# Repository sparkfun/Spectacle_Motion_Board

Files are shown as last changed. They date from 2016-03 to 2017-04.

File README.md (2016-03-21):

SparkFun AutoDriver Libraries
==========

Libraries for using the AutoDriver in various environments

Directory Contents
-------------------
* **/Arduino** - [Arduino IDE](http://www.arduino.cc/en/Main/Software) library and example files

License Information
-------------------
This product is open source! 
The code is beerware; if you see me (or any other SparkFun employee) at the local, and you've found our code helpful, please buy us a round!
Please use, reuse, and modify these files as you see fit. Please maintain attribution to SparkFun Electronics and release anything derivative under the same license.

Distributed as-is; no warranty is given.

- Your friends at SparkFun.

BUILD INSTRUCTIONS:
---------------------
While we make every effort to keep our library repositories up-to-date with the product repositories, it may be a good idea to update the libraries to the latest version.

To get the most up-to-date version of the library, you must use the following git subtree commands.

git subtree add -P Libraries/Arduino --squash https://github.com/sparkfun/SparkFun_AutoDriver_Arduino_Library master

git subtree pull -P Libraries/Arduino --squash https://github.com/sparkfun/SparkFun_AutoDriver_Arduino_Library master

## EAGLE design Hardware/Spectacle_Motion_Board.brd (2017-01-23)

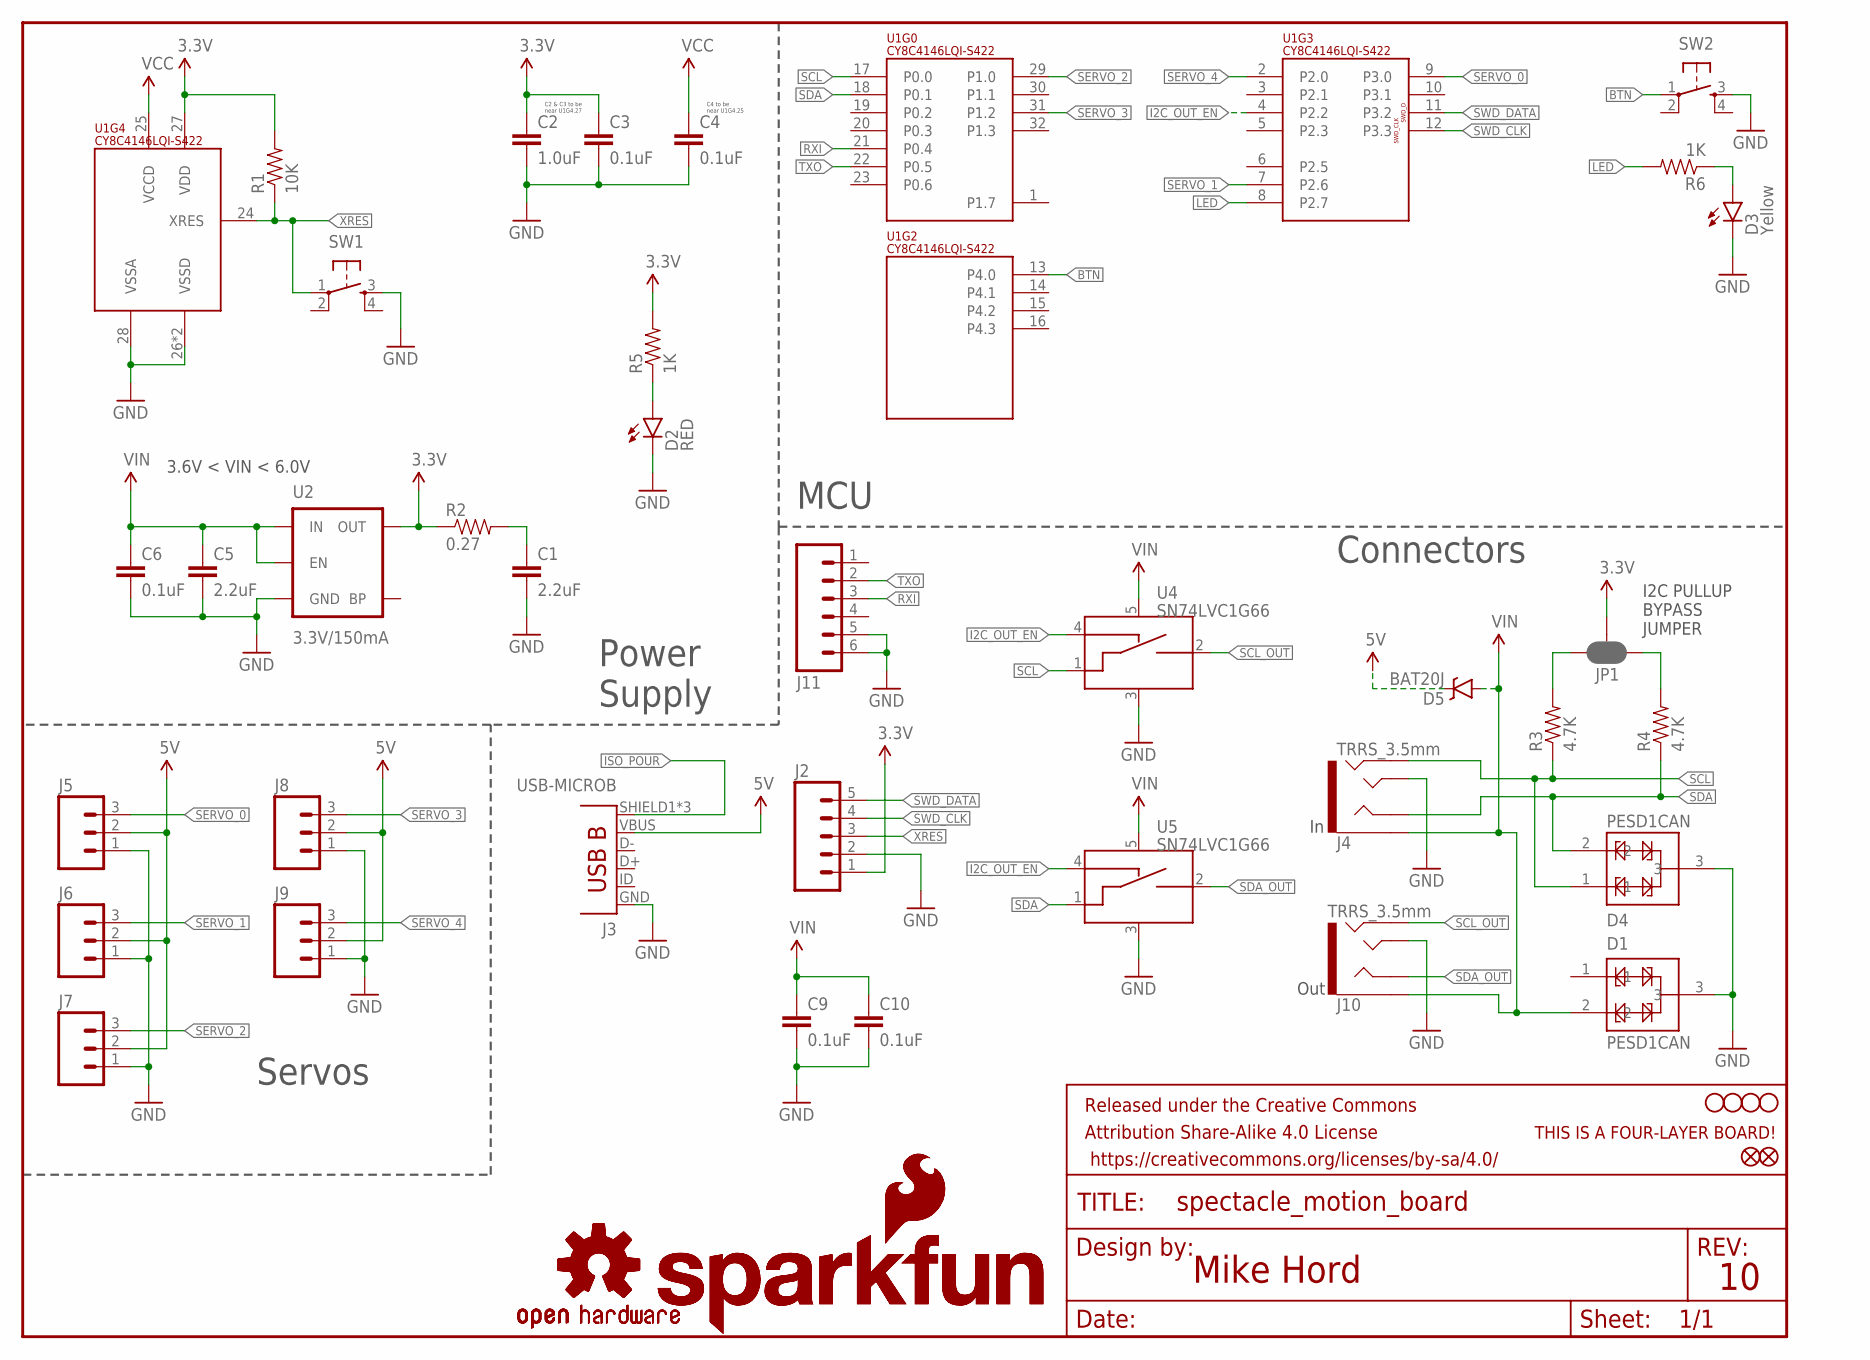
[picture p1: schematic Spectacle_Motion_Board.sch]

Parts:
C1, C5: 2.2uF; 0603-CAP
C2: 1.0uF; 0402-CAP
C3, C4, C6, C9, C10: 0.1uF; 0402-CAP
D1, D4: PESD1CAN; SOT23-3
D2: RED; LED-0603
D3: Yellow; LED-0603
D5: BAT20J; SOD-323
FD1, FD2: FIDUCIALUFIDUCIAL; MICRO-FIDUCIAL
FRAME1: FRAME-LETTER; CREATIVE_COMMONS
H1, H2, H3, H4: STAND-OFF
J2: M05NO_SILK; 1X05_NO_SILK
J3: USB-MICROB; USB-B-MICRO-SMD_V03_RED_PASTE
J4, J10: TRRS_3.5mm; AUDIO_JACK_3.5MM_TRRS_SMD_RA
J5, J6, J7, J8, J9: M03LOCK; 1X03_LOCK
J11: M06NO_SILK_NO_POP; 1X06_NO_SILK
JP1: JUMPER-PAD-3-NC_BY_PASTE; PAD-JUMPER-3-NC_BY_PASTE_YES_SILK_FULL_BOX
LOGO1, LOGO4: OSHW-LOGOS; OSHW-LOGO-S
LOGO2, LOGO3: SFE_LOGO_NAME_FLAME.1_INCH; SFE_LOGO_NAME_FLAME_.1
R1: 10K; 0603-RES
R2: 0.27; 0603-RES
R3, R4: 4.7K; 0603-RES
R5, R6: 1K; 0603-RES
SW1, SW2: SWITCH_SPST_4_PINRECT; TACTILE_SWITCH_SMD_4.6X2.8MM
U1: CY8C4146LQI-S422; QFN-32
U2: 3.3V/150mA; SOT23-5
U4, U5: SN74LVC1G66; SOT23-5
U$1: FOUR_LAYER_WARNING

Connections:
3.3V: C2.1, C3.1, J2.1, JP1.2, R1.2, R2.1, R5.2, U1.27 (VDD), U2.5 (OUT)
5V: D5.C, J3.VBUS, J5.2, J6.2, J7.2, J8.2, J9.2
BTN: SW2.1, U1.13 (P4.0)
GND: C1.2, C2.2, C3.2, C4.2, C5.2, C6.2, C9.2, C10.2, D1.3, D2.C, D3.C, D4.3, J2.2, J3.GND, J4.TIP, J5.1, J6.1, J7.1, J8.1, J9.1, J10.TIP, J11.5, J11.6, SW1.3, SW2.3, U1.26 (VSSD), U1.28 (VSSA), U1.EP (VSSD), U2.2 (GND), U4.3 (VSS), U5.3 (VSS)
I2C_OUT_EN: U1.4 (P2.2), U4.4 (CTRL_IN), U5.4 (CTRL_IN)
ISO_POUR: J3.SHIELD1 (SHIELD), J3.SHIELD2 (SHIELD), J3.SHIELD3 (SHIELD)
LED: R6.2, U1.8 (P2.7)
unnamed: JP1.3, R3.2
unnamed: C1.1, R2.2
unnamed: D2.A, R5.1
unnamed: D3.A, R6.1
unnamed: JP1.1, R4.2
RXI: J11.3, U1.21 (P0.4)
SCL: D4.1, J4.RING2, R3.1, U1.17 (P0.0), U4.1 (A_IN)
SCL_OUT: J10.RING2, U4.2 (A_OUT)
SDA: D4.2, J4.RING1, R4.1, U1.18 (P0.1), U5.1 (A_IN)
SDA_OUT: J10.RING1, U5.2 (A_OUT)
SERVO_0: J5.3, U1.9 (P3.0)
SERVO_1: J6.3, U1.7 (P2.6)
SERVO_2: J7.3, U1.29 (P1.0)
SERVO_3: J8.3, U1.31 (P1.2)
SERVO_4: J9.3, U1.2 (P2.0)
SWD_CLK: J2.4, U1.12 (P3.3)
SWD_DATA: J2.5, U1.11 (P3.2)
TXO: J11.2, U1.22 (P0.5)
VCC: C4.1, U1.25 (VCCD)
VIN: C5.1, C6.1, C9.1, C10.1, D1.2, D5.A, J4.EARTH, J10.EARTH, U2.1 (IN), U2.3 (EN), U4.5 (VCC), U5.5 (VCC)
XRES: J2.3, R1.1, SW1.1, U1.24 (XRES)

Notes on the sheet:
C2 & C3 to be near U1G4.27
C4 to be near U1G4.25
Mike Hord
MCU
Connectors
Servos
Power Supply
3.6V < VIN < 6.0V
I2C PULLUP BYPASS JUMPER
Out

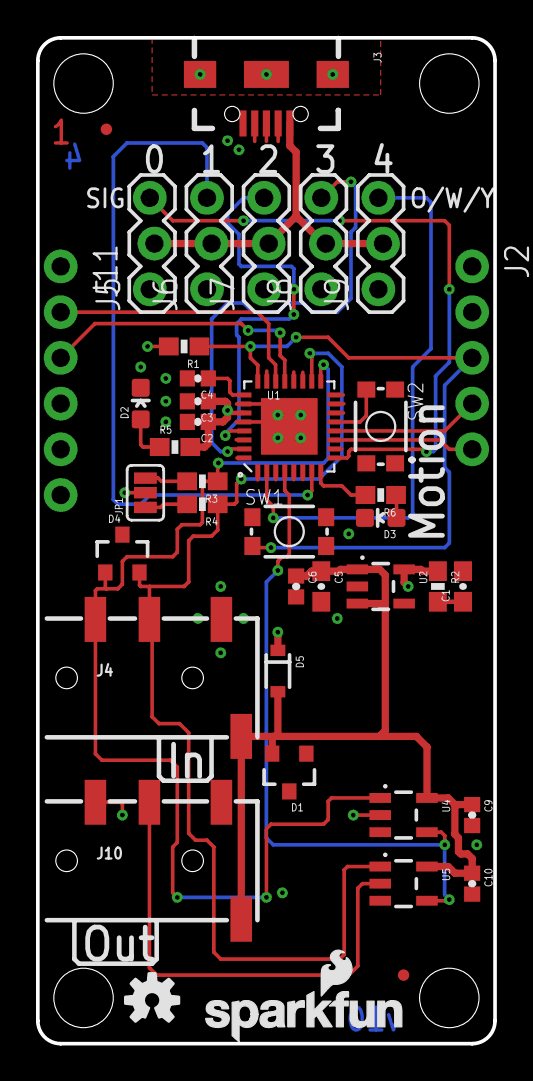
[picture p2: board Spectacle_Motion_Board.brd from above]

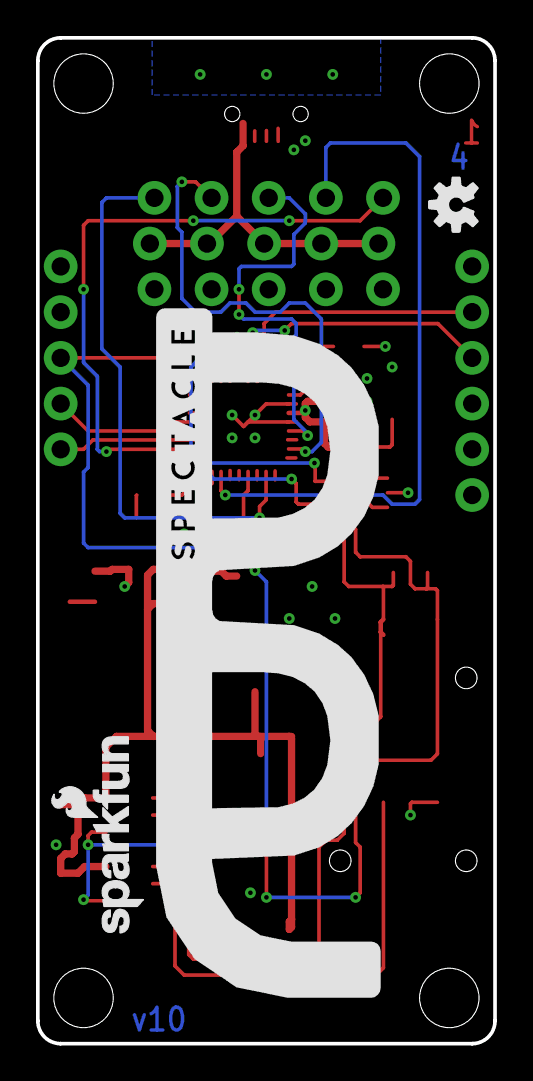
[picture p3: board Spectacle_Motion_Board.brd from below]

Board: 4 copper layers, 25.4 x 55.9 mm, 49 parts (3 on the bottom side), 28 nets.

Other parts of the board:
U$3: SPECTACLE_LOGO_NEGATIVE_1.5X0.5

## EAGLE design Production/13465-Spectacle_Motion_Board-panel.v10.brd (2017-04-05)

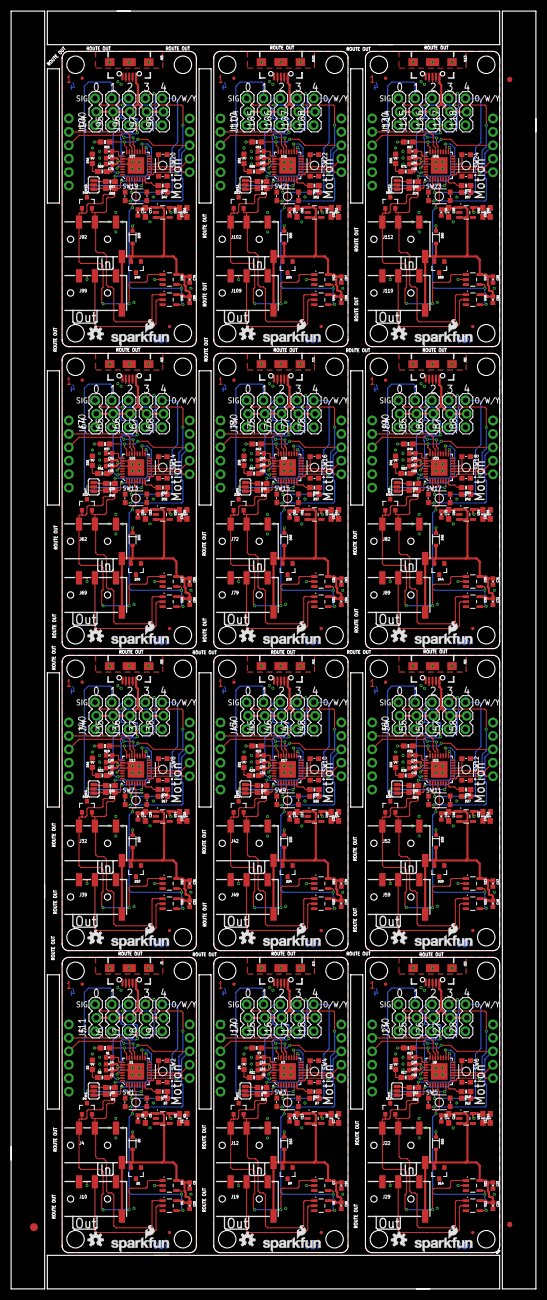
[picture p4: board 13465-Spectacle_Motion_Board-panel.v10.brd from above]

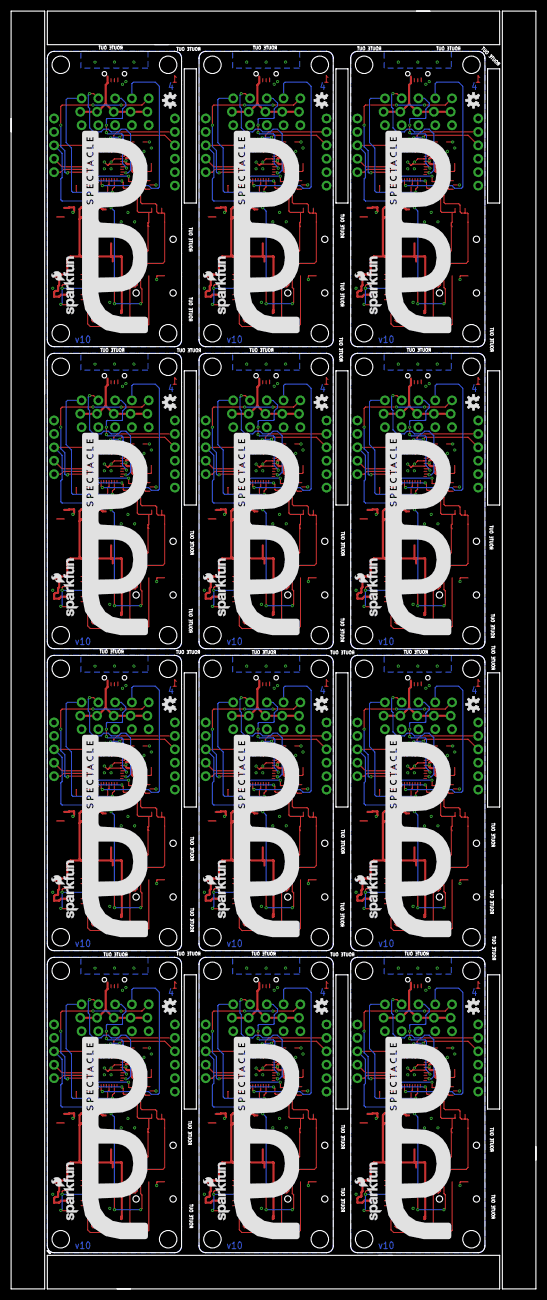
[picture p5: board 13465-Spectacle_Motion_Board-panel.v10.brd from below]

Board: 4 copper layers, 99.3 x 241.8 mm, 567 parts (36 on the bottom side), 336 nets.

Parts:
C1, C5, C7, C13, C17, C21, C25, C29, C33, C37, C41, C45, C49, C53, C57, C61, C65, C69, C73, C77, C81, C85, C89, C93: 2.2uF; 0603-CAP
C2, C8, C18, C26, C34, C42, C50, C58, C66, C74, C82, C90: 1.0uF; 0402-CAP
C3, C4, C6, C9, C10, C11, C12, C14, C15, C16, C19, C20, C22, C23, C24, C27, C28, C30, C31, C32, C35, C36, C38, C39, C40, C43, C44, C46, C47, C48, C51, C52, C54, C55, C56, C59, C60, C62, C63, C64, C67, C68, C70, C71, C72, C75, C76, C78, C79, C80, C83, C84, C86, C87, C88, C91, C92, C94, C95, C96: 0.1uF; 0402-CAP
D1, D4, D8, D9, D13, D14, D18, D19, D23, D24, D28, D29, D33, D34, D38, D39, D43, D44, D48, D49, D53, D54, D58, D59: PESD1CAN; SOT23-3
D2, D6, D11, D16, D21, D26, D31, D36, D41, D46, D51, D56: RED; LED-0603
D3, D7, D12, D17, D22, D27, D32, D37, D42, D47, D52, D57: Yellow; LED-0603
D5, D10, D15, D20, D25, D30, D35, D40, D45, D50, D55, D60: BAT20J; SOD-323
E$1: FIDUCIAL-1.5X3
E$7, E$8: FIDUCIAL-1X2
FD1, FD2, FD3, FD4, FD5, FD6, FD7, FD8, FD9, FD10, FD11, FD12, FD13, FD14, FD15, FD16, FD17, FD18, FD19, FD20, FD21, FD22, FD23, FD24: FIDUCIALUFIDUCIAL; MICRO-FIDUCIAL
H1, H2, H3, H4, H5, H6, H7, H8, H9, H10, H11, H12, H13, H14, H15, H16, H17, H18, H19, H20, H21, H22, H23, H24, H25, H26, H27, H28, H29, H30, H31, H32, H33, H34, H35, H36, H37, H38, H39, H40, H41, H42, H43, H44, H45, H46, H47, H48: STAND-OFF
J1, J2, J21, J31, J41, J51, J61, J71, J81, J91, J101, J111: 1X05_NO_SILK
J3, J13, J23, J33, J43, J53, J63, J73, J83, J93, J103, J113: USB-MICROB; USB-B-MICRO-SMD_V03_RED_PASTE
J4, J10, J12, J19, J22, J29, J32, J39, J42, J49, J52, J59, J62, J69, J72, J79, J82, J89, J92, J99, J102, J109, J112, J119: TRRS_3.5mm; AUDIO_JACK_3.5MM_TRRS_SMD_RA
J5, J6, J7, J8, J9, J14, J15, J16, J17, J18, J24, J25, J26, J27, J28, J34, J35, J36, J37, J38, J44, J45, J46, J47, J48, J54, J55, J56, J57, J58, J64, J65, J66, J67, J68, J74, J75, J76, J77, J78, J84, J85, J86, J87, J88, J94, J95, J96, J97, J98, J104, J105, J106, J107, J108, J114, J115, J116, J117, J118: 1X03_LOCK
J11, J20, J30, J40, J50, J60, J70, J80, J90, J100, J110, J120: 1X06_NO_SILK
JP1, JP2, JP3, JP4, JP5, JP6, JP7, JP8, JP9, JP10, JP11, JP12: JUMPER-PAD-3-NC_BY_PASTE; PAD-JUMPER-3-NC_BY_PASTE_YES_SILK_FULL_BOX
LOGO1, LOGO4, LOGO5, LOGO8, LOGO9, LOGO12, LOGO13, LOGO16, LOGO17, LOGO20, LOGO21, LOGO24, LOGO25, LOGO28, LOGO29, LOGO32, LOGO33, LOGO36, LOGO37, LOGO40, LOGO41, LOGO44, LOGO45, LOGO48: OSHW-LOGOS; OSHW-LOGO-S
LOGO2, LOGO3, LOGO6, LOGO7, LOGO10, LOGO11, LOGO14, LOGO15, LOGO18, LOGO19, LOGO22, LOGO23, LOGO26, LOGO27, LOGO30, LOGO31, LOGO34, LOGO35, LOGO38, LOGO39, LOGO42, LOGO43, LOGO46, LOGO47: SFE_LOGO_NAME_FLAME.1_INCH; SFE_LOGO_NAME_FLAME_.1
R1, R7, R13, R19, R25, R31, R37, R43, R49, R55, R61, R67: 10K; 0603-RES
R2, R8, R14, R20, R26, R32, R38, R44, R50, R56, R62, R68: 0.27; 0603-RES
R3, R4, R9, R10, R15, R16, R21, R22, R27, R28, R33, R34, R39, R40, R45, R46, R51, R52, R57, R58, R63, R64, R69, R70: 4.7K; 0603-RES
R5, R6, R11, R12, R17, R18, R23, R24, R29, R30, R35, R36, R41, R42, R47, R48, R53, R54, R59, R60, R65, R66, R71, R72: 1K; 0603-RES
SW1, SW2, SW3, SW4, SW5, SW6, SW7, SW8, SW9, SW10, SW11, SW12, SW13, SW14, SW15, SW16, SW17, SW18, SW19, SW20, SW21, SW22, SW23, SW24: TACTILE_SWITCH_SMD_4.6X2.8MM
U1, U3, U9, U13, U17, U21, U25, U29, U33, U37, U41, U45: CY8C4146LQI-S422; QFN-32
U2, U6, U10, U14, U18, U22, U26, U30, U34, U38, U42, U46: 3.3V/150mA; SOT23-5
U4, U5, U7, U8, U11, U12, U15, U16, U19, U20, U23, U24, U27, U28, U31, U32, U35, U36, U39, U40, U43, U44, U47, U48: SN74LVC1G66; SOT23-5
U$1, U$2, U$3, U$4, U$5, U$6, U$7, U$8, U$9, U$10, U$11, U$12: SPECTACLE_LOGO_NEGATIVE_1.5X0.5

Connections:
3.3V: C2.1, C3.1, J2.1, JP1.2, R1.2, R2.1, R5.2, U1.27, U2.5
3.3V1: C8.1, C11.1, J1.1, JP2.2, R7.2, R8.1, R11.2, U3.27, U6.5
3.3V2: C18.1, C19.1, J21.1, JP3.2, R13.2, R14.1, R17.2, U9.27, U10.5
3.3V3: C26.1, C27.1, J31.1, JP4.2, R19.2, R20.1, R23.2, U13.27, U14.5
3.3V4: C34.1, C35.1, J41.1, JP5.2, R25.2, R26.1, R29.2, U17.27, U18.5
3.3V5: C42.1, C43.1, J51.1, JP6.2, R31.2, R32.1, R35.2, U21.27, U22.5
3.3V6: C50.1, C51.1, J61.1, JP7.2, R37.2, R38.1, R41.2, U25.27, U26.5
3.3V7: C58.1, C59.1, J71.1, JP8.2, R43.2, R44.1, R47.2, U29.27, U30.5
3.3V8: C66.1, C67.1, J81.1, JP9.2, R49.2, R50.1, R53.2, U33.27, U34.5
3.3V9: C74.1, C75.1, J91.1, JP10.2, R55.2, R56.1, R59.2, U37.27, U38.5
3.3V10: C82.1, C83.1, J101.1, JP11.2, R61.2, R62.1, R65.2, U41.27, U42.5
3.3V11: C90.1, C91.1, J111.1, JP12.2, R67.2, R68.1, R71.2, U45.27, U46.5
5V: D5.C, J3.VBUS, J5.2, J6.2, J7.2, J8.2, J9.2
5V1: D10.C, J13.VBUS, J14.2, J15.2, J16.2, J17.2, J18.2
5V2: D15.C, J23.VBUS, J24.2, J25.2, J26.2, J27.2, J28.2
5V3: D20.C, J33.VBUS, J34.2, J35.2, J36.2, J37.2, J38.2
5V4: D25.C, J43.VBUS, J44.2, J45.2, J46.2, J47.2, J48.2
5V5: D30.C, J53.VBUS, J54.2, J55.2, J56.2, J57.2, J58.2
5V6: D35.C, J63.VBUS, J64.2, J65.2, J66.2, J67.2, J68.2
5V7: D40.C, J73.VBUS, J74.2, J75.2, J76.2, J77.2, J78.2
5V8: D45.C, J83.VBUS, J84.2, J85.2, J86.2, J87.2, J88.2
5V9: D50.C, J93.VBUS, J94.2, J95.2, J96.2, J97.2, J98.2
5V10: D55.C, J103.VBUS, J104.2, J105.2, J106.2, J107.2, J108.2
5V11: D60.C, J113.VBUS, J114.2, J115.2, J116.2, J117.2, J118.2
BTN: SW2.1, U1.13
BTN1: SW4.1, U3.13
BTN2: SW6.1, U9.13
BTN3: SW8.1, U13.13
BTN4: SW10.1, U17.13
BTN5: SW12.1, U21.13
BTN6: SW14.1, U25.13
BTN7: SW16.1, U29.13
BTN8: SW18.1, U33.13
BTN9: SW20.1, U37.13
BTN10: SW22.1, U41.13
BTN11: SW24.1, U45.13
GND: C1.2, C2.2, C3.2, C4.2, C5.2, C6.2, C9.2, C10.2, D1.3, D2.C, D3.C, D4.3, J2.2, J3.GND, J4.TIP, J5.1, J6.1, J7.1, J8.1, J9.1, J10.TIP, J11.5, J11.6, SW1.3, SW2.3, U1.26, U1.28, U1.EP, U2.2, U4.3, U5.3
GND1: C7.2, C8.2, C11.2, C12.2, C13.2, C14.2, C15.2, C16.2, D6.C, D7.C, D8.3, D9.3, J1.2, J12.TIP, J13.GND, J14.1, J15.1, J16.1, J17.1, J18.1, J19.TIP, J20.5, J20.6, SW3.3, SW4.3, U3.26, U3.28, U3.EP, U6.2, U7.3, U8.3
GND2: C17.2, C18.2, C19.2, C20.2, C21.2, C22.2, C23.2, C24.2, D11.C, D12.C, D13.3, D14.3, J21.2, J22.TIP, J23.GND, J24.1, J25.1, J26.1, J27.1, J28.1, J29.TIP, J30.5, J30.6, SW5.3, SW6.3, U9.26, U9.28, U9.EP, U10.2, U11.3, U12.3
GND3: C25.2, C26.2, C27.2, C28.2, C29.2, C30.2, C31.2, C32.2, D16.C, D17.C, D18.3, D19.3, J31.2, J32.TIP, J33.GND, J34.1, J35.1, J36.1, J37.1, J38.1, J39.TIP, J40.5, J40.6, SW7.3, SW8.3, U13.26, U13.28, U13.EP, U14.2, U15.3, U16.3
GND4: C33.2, C34.2, C35.2, C36.2, C37.2, C38.2, C39.2, C40.2, D21.C, D22.C, D23.3, D24.3, J41.2, J42.TIP, J43.GND, J44.1, J45.1, J46.1, J47.1, J48.1, J49.TIP, J50.5, J50.6, SW9.3, SW10.3, U17.26, U17.28, U17.EP, U18.2, U19.3, U20.3
GND5: C41.2, C42.2, C43.2, C44.2, C45.2, C46.2, C47.2, C48.2, D26.C, D27.C, D28.3, D29.3, J51.2, J52.TIP, J53.GND, J54.1, J55.1, J56.1, J57.1, J58.1, J59.TIP, J60.5, J60.6, SW11.3, SW12.3, U21.26, U21.28, U21.EP, U22.2, U23.3, U24.3
GND6: C49.2, C50.2, C51.2, C52.2, C53.2, C54.2, C55.2, C56.2, D31.C, D32.C, D33.3, D34.3, J61.2, J62.TIP, J63.GND, J64.1, J65.1, J66.1, J67.1, J68.1, J69.TIP, J70.5, J70.6, SW13.3, SW14.3, U25.26, U25.28, U25.EP, U26.2, U27.3, U28.3
GND7: C57.2, C58.2, C59.2, C60.2, C61.2, C62.2, C63.2, C64.2, D36.C, D37.C, D38.3, D39.3, J71.2, J72.TIP, J73.GND, J74.1, J75.1, J76.1, J77.1, J78.1, J79.TIP, J80.5, J80.6, SW15.3, SW16.3, U29.26, U29.28, U29.EP, U30.2, U31.3, U32.3
GND8: C65.2, C66.2, C67.2, C68.2, C69.2, C70.2, C71.2, C72.2, D41.C, D42.C, D43.3, D44.3, J81.2, J82.TIP, J83.GND, J84.1, J85.1, J86.1, J87.1, J88.1, J89.TIP, J90.5, J90.6, SW17.3, SW18.3, U33.26, U33.28, U33.EP, U34.2, U35.3, U36.3
GND9: C73.2, C74.2, C75.2, C76.2, C77.2, C78.2, C79.2, C80.2, D46.C, D47.C, D48.3, D49.3, J91.2, J92.TIP, J93.GND, J94.1, J95.1, J96.1, J97.1, J98.1, J99.TIP, J100.5, J100.6, SW19.3, SW20.3, U37.26, U37.28, U37.EP, U38.2, U39.3, U40.3
GND10: C81.2, C82.2, C83.2, C84.2, C85.2, C86.2, C87.2, C88.2, D51.C, D52.C, D53.3, D54.3, J101.2, J102.TIP, J103.GND, J104.1, J105.1, J106.1, J107.1, J108.1, J109.TIP, J110.5, J110.6, SW21.3, SW22.3, U41.26, U41.28, U41.EP, U42.2, U43.3, U44.3
GND11: C89.2, C90.2, C91.2, C92.2, C93.2, C94.2, C95.2, C96.2, D56.C, D57.C, D58.3, D59.3, J111.2, J112.TIP, J113.GND, J114.1, J115.1, J116.1, J117.1, J118.1, J119.TIP, J120.5, J120.6, SW23.3, SW24.3, U45.26, U45.28, U45.EP, U46.2, U47.3, U48.3
I2C_OUT_EN: U1.4, U4.4, U5.4
I2C_OUT_EN1: U3.4, U7.4, U8.4
I2C_OUT_EN2: U9.4, U11.4, U12.4
I2C_OUT_EN3: U13.4, U15.4, U16.4
I2C_OUT_EN4: U17.4, U19.4, U20.4
I2C_OUT_EN5: U21.4, U23.4, U24.4
I2C_OUT_EN6: U25.4, U27.4, U28.4
I2C_OUT_EN7: U29.4, U31.4, U32.4
I2C_OUT_EN8: U33.4, U35.4, U36.4
I2C_OUT_EN9: U37.4, U39.4, U40.4
I2C_OUT_EN10: U41.4, U43.4, U44.4
I2C_OUT_EN11: U45.4, U47.4, U48.4
ISO_POUR: J3.SHIELD1, J3.SHIELD2, J3.SHIELD3
ISO_POUR1: J13.SHIELD1, J13.SHIELD2, J13.SHIELD3
ISO_POUR2: J23.SHIELD1, J23.SHIELD2, J23.SHIELD3
ISO_POUR3: J33.SHIELD1, J33.SHIELD2, J33.SHIELD3
ISO_POUR4: J43.SHIELD1, J43.SHIELD2, J43.SHIELD3
ISO_POUR5: J53.SHIELD1, J53.SHIELD2, J53.SHIELD3
ISO_POUR6: J63.SHIELD1, J63.SHIELD2, J63.SHIELD3
ISO_POUR7: J73.SHIELD1, J73.SHIELD2, J73.SHIELD3
ISO_POUR8: J83.SHIELD1, J83.SHIELD2, J83.SHIELD3
ISO_POUR9: J93.SHIELD1, J93.SHIELD2, J93.SHIELD3
ISO_POUR10: J103.SHIELD1, J103.SHIELD2, J103.SHIELD3
ISO_POUR11: J113.SHIELD1, J113.SHIELD2, J113.SHIELD3
LED: R6.2, U1.8
LED1: R12.2, U3.8
LED2: R18.2, U9.8
LED3: R24.2, U13.8
LED4: R30.2, U17.8
LED5: R36.2, U21.8
LED6: R42.2, U25.8
LED7: R48.2, U29.8
LED8: R54.2, U33.8
LED9: R60.2, U37.8
LED10: R66.2, U41.8
LED11: R72.2, U45.8
unnamed: JP1.3, R3.2
unnamed: C1.1, R2.2
unnamed: D2.A, R5.1
unnamed: D3.A, R6.1
unnamed: JP1.1, R4.2
unnamed: C7.1, R8.2
unnamed: JP2.3, R9.2
unnamed: JP2.1, R10.2
unnamed: D6.A, R11.1
unnamed: D7.A, R12.1
unnamed: C17.1, R14.2
unnamed: JP3.3, R15.2
unnamed: JP3.1, R16.2
unnamed: D11.A, R17.1
unnamed: D12.A, R18.1
unnamed: C25.1, R20.2
unnamed: JP4.3, R21.2
unnamed: JP4.1, R22.2
unnamed: D16.A, R23.1
unnamed: D17.A, R24.1
unnamed: C33.1, R26.2
unnamed: JP5.3, R27.2
unnamed: JP5.1, R28.2
unnamed: D21.A, R29.1
unnamed: D22.A, R30.1
unnamed: C41.1, R32.2
unnamed: JP6.3, R33.2
unnamed: JP6.1, R34.2
unnamed: D26.A, R35.1
unnamed: D27.A, R36.1
unnamed: C49.1, R38.2
unnamed: JP7.3, R39.2
unnamed: JP7.1, R40.2
unnamed: D31.A, R41.1
unnamed: D32.A, R42.1
unnamed: C57.1, R44.2
unnamed: JP8.3, R45.2
unnamed: JP8.1, R46.2
unnamed: D36.A, R47.1
unnamed: D37.A, R48.1
unnamed: C65.1, R50.2
unnamed: JP9.3, R51.2
unnamed: JP9.1, R52.2
unnamed: D41.A, R53.1
unnamed: D42.A, R54.1
unnamed: C73.1, R56.2
unnamed: JP10.3, R57.2
unnamed: JP10.1, R58.2
unnamed: D46.A, R59.1
unnamed: D47.A, R60.1
unnamed: C81.1, R62.2
unnamed: JP11.3, R63.2
unnamed: JP11.1, R64.2
unnamed: D51.A, R65.1
unnamed: D52.A, R66.1
unnamed: C89.1, R68.2
unnamed: JP12.3, R69.2
unnamed: JP12.1, R70.2
unnamed: D56.A, R71.1
unnamed: D57.A, R72.1
RXI: J11.3, U1.21
RXI1: J20.3, U3.21
RXI2: J30.3, U9.21
RXI3: J40.3, U13.21
RXI4: J50.3, U17.21
RXI5: J60.3, U21.21
RXI6: J70.3, U25.21
RXI7: J80.3, U29.21
RXI8: J90.3, U33.21
RXI9: J100.3, U37.21
RXI10: J110.3, U41.21
RXI11: J120.3, U45.21
SCL: D4.1, J4.RING2, R3.1, U1.17, U4.1
SCL1: D8.1, J12.RING2, R9.1, U3.17, U7.1
SCL2: D13.1, J22.RING2, R15.1, U9.17, U11.1
SCL3: D18.1, J32.RING2, R21.1, U13.17, U15.1
SCL4: D23.1, J42.RING2, R27.1, U17.17, U19.1
SCL5: D28.1, J52.RING2, R33.1, U21.17, U23.1
SCL6: D33.1, J62.RING2, R39.1, U25.17, U27.1
SCL7: D38.1, J72.RING2, R45.1, U29.17, U31.1
SCL8: D43.1, J82.RING2, R51.1, U33.17, U35.1
SCL9: D48.1, J92.RING2, R57.1, U37.17, U39.1
SCL10: D53.1, J102.RING2, R63.1, U41.17, U43.1
SCL11: D58.1, J112.RING2, R69.1, U45.17, U47.1
SCL_OUT: J10.RING2, U4.2
SCL_OUT1: J19.RING2, U7.2
SCL_OUT2: J29.RING2, U11.2
SCL_OUT3: J39.RING2, U15.2
SCL_OUT4: J49.RING2, U19.2
SCL_OUT5: J59.RING2, U23.2
SCL_OUT6: J69.RING2, U27.2
SCL_OUT7: J79.RING2, U31.2
SCL_OUT8: J89.RING2, U35.2
SCL_OUT9: J99.RING2, U39.2
SCL_OUT10: J109.RING2, U43.2
SCL_OUT11: J119.RING2, U47.2
SDA: D4.2, J4.RING1, R4.1, U1.18, U5.1
SDA1: D8.2, J12.RING1, R10.1, U3.18, U8.1
SDA2: D13.2, J22.RING1, R16.1, U9.18, U12.1
SDA3: D18.2, J32.RING1, R22.1, U13.18, U16.1
SDA4: D23.2, J42.RING1, R28.1, U17.18, U20.1
SDA5: D28.2, J52.RING1, R34.1, U21.18, U24.1
SDA6: D33.2, J62.RING1, R40.1, U25.18, U28.1
SDA7: D38.2, J72.RING1, R46.1, U29.18, U32.1
SDA8: D43.2, J82.RING1, R52.1, U33.18, U36.1
SDA9: D48.2, J92.RING1, R58.1, U37.18, U40.1
SDA10: D53.2, J102.RING1, R64.1, U41.18, U44.1
SDA11: D58.2, J112.RING1, R70.1, U45.18, U48.1
SDA_OUT: J10.RING1, U5.2
SDA_OUT1: J19.RING1, U8.2
SDA_OUT2: J29.RING1, U12.2
SDA_OUT3: J39.RING1, U16.2
SDA_OUT4: J49.RING1, U20.2
SDA_OUT5: J59.RING1, U24.2
SDA_OUT6: J69.RING1, U28.2
SDA_OUT7: J79.RING1, U32.2
SDA_OUT8: J89.RING1, U36.2
SDA_OUT9: J99.RING1, U40.2
SDA_OUT10: J109.RING1, U44.2
SDA_OUT11: J119.RING1, U48.2
SERVO_0: J5.3, U1.9
SERVO_1: J6.3, U1.7
SERVO_2: J7.3, U1.29
SERVO_3: J8.3, U1.31
SERVO_4: J9.3, U1.2
SERVO_5: J14.3, U3.9
SERVO_6: J15.3, U3.7
SERVO_7: J16.3, U3.29
SERVO_8: J17.3, U3.31
SERVO_9: J18.3, U3.2
SERVO_10: J24.3, U9.9
SERVO_11: J25.3, U9.7
SERVO_12: J26.3, U9.29
SERVO_13: J27.3, U9.31
SERVO_14: J28.3, U9.2
SERVO_15: J34.3, U13.9
SERVO_16: J35.3, U13.7
SERVO_17: J36.3, U13.29
SERVO_18: J37.3, U13.31
SERVO_19: J38.3, U13.2
SERVO_20: J44.3, U17.9
SERVO_21: J45.3, U17.7
SERVO_22: J46.3, U17.29
SERVO_23: J47.3, U17.31
SERVO_24: J48.3, U17.2
SERVO_25: J54.3, U21.9
SERVO_26: J55.3, U21.7
SERVO_27: J56.3, U21.29
SERVO_28: J57.3, U21.31
SERVO_29: J58.3, U21.2
SERVO_30: J64.3, U25.9
SERVO_31: J65.3, U25.7
SERVO_32: J66.3, U25.29
SERVO_33: J67.3, U25.31
SERVO_34: J68.3, U25.2
SERVO_35: J74.3, U29.9
SERVO_36: J75.3, U29.7
SERVO_37: J76.3, U29.29
SERVO_38: J77.3, U29.31
SERVO_39: J78.3, U29.2
SERVO_40: J84.3, U33.9
SERVO_41: J85.3, U33.7
SERVO_42: J86.3, U33.29
SERVO_43: J87.3, U33.31
SERVO_44: J88.3, U33.2
SERVO_45: J94.3, U37.9
SERVO_46: J95.3, U37.7
SERVO_47: J96.3, U37.29
SERVO_48: J97.3, U37.31
SERVO_49: J98.3, U37.2
SERVO_50: J104.3, U41.9
SERVO_51: J105.3, U41.7
SERVO_52: J106.3, U41.29
SERVO_53: J107.3, U41.31
SERVO_54: J108.3, U41.2
SERVO_55: J114.3, U45.9
SERVO_56: J115.3, U45.7
SERVO_57: J116.3, U45.29
SERVO_58: J117.3, U45.31
SERVO_59: J118.3, U45.2
SWD_CLK: J2.4, U1.12
SWD_CLK1: J1.4, U3.12
SWD_CLK2: J21.4, U9.12
SWD_CLK3: J31.4, U13.12
SWD_CLK4: J41.4, U17.12
SWD_CLK5: J51.4, U21.12
SWD_CLK6: J61.4, U25.12
SWD_CLK7: J71.4, U29.12
SWD_CLK8: J81.4, U33.12
SWD_CLK9: J91.4, U37.12
SWD_CLK10: J101.4, U41.12
SWD_CLK11: J111.4, U45.12
SWD_DATA: J2.5, U1.11
SWD_DATA1: J1.5, U3.11
SWD_DATA2: J21.5, U9.11
SWD_DATA3: J31.5, U13.11
SWD_DATA4: J41.5, U17.11
SWD_DATA5: J51.5, U21.11
SWD_DATA6: J61.5, U25.11
SWD_DATA7: J71.5, U29.11
SWD_DATA8: J81.5, U33.11
SWD_DATA9: J91.5, U37.11
SWD_DATA10: J101.5, U41.11
SWD_DATA11: J111.5, U45.11
TXO: J11.2, U1.22
TXO1: J20.2, U3.22
TXO2: J30.2, U9.22
TXO3: J40.2, U13.22
TXO4: J50.2, U17.22
TXO5: J60.2, U21.22
TXO6: J70.2, U25.22
TXO7: J80.2, U29.22
TXO8: J90.2, U33.22
TXO9: J100.2, U37.22
TXO10: J110.2, U41.22
TXO11: J120.2, U45.22
VCC: C4.1, U1.25
VCC1: C12.1, U3.25
VCC2: C20.1, U9.25
VCC3: C28.1, U13.25
VCC4: C36.1, U17.25
VCC5: C44.1, U21.25
VCC6: C52.1, U25.25
VCC7: C60.1, U29.25
VCC8: C68.1, U33.25
VCC9: C76.1, U37.25
VCC10: C84.1, U41.25
VCC11: C92.1, U45.25
VIN: C5.1, C6.1, C9.1, C10.1, D1.2, D5.A, J4.EARTH, J10.EARTH, U2.1, U2.3, U4.5, U5.5
VIN1: C13.1, C14.1, C15.1, C16.1, D9.2, D10.A, J12.EARTH, J19.EARTH, U6.1, U6.3, U7.5, U8.5
VIN2: C21.1, C22.1, C23.1, C24.1, D14.2, D15.A, J22.EARTH, J29.EARTH, U10.1, U10.3, U11.5, U12.5
VIN3: C29.1, C30.1, C31.1, C32.1, D19.2, D20.A, J32.EARTH, J39.EARTH, U14.1, U14.3, U15.5, U16.5
VIN4: C37.1, C38.1, C39.1, C40.1, D24.2, D25.A, J42.EARTH, J49.EARTH, U18.1, U18.3, U19.5, U20.5
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

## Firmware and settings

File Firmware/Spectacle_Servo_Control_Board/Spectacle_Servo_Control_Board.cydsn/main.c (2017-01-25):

/****************************************************************************
main.c
Main code file for Spectacle motion output board project
Mike Hord @ SparkFun Electronics
24 Jan 2017
https://github.com/sparkfun/Spectacle_Motion_Board

This file includes main(), which configures the hardware for the system as
well as monitoring the data coming from the director board.

Development environment specifics:
Developed in PSoC Creator 4.0

This code is beerware; if you see me (or any other SparkFun employee) at the
local, and you've found our code helpful, please buy us a round!
****************************************************************************/

#include <project.h>
#include <stdbool.h>
#include <string.h>
#include <stdlib.h>
#include <stdio.h>
#include "servo.h"
#include "programming.h"
#include "spectacle.h"

#define I2C_BUFFER_SIZE 256
#define I2C_BUFFER_RW_BOUNDARY 256

// systemTimer is incremented in the tickISR, which occurs once a millisecond.
//  It's the timebase for the entire firmware, upon which all other timing
//  is based.
volatile int32 systemTimer = 0;
CY_ISR_PROTO(tickISR);

// servo is a struct which tracks the desired behavior of a single channel. A
// single motor may have more than one servo struct associated with it, but
// only one servo struct should associate with a channel coming into the board.
// behaviors is the list of behaviors that the director board has passed into
// the servo board.
struct servo *behaviors;

// behaviorListLen is the variable which tracks the number of behaviors that
// the director board has passed into the servo board. During normal operation,
// we will iterate over the object 'behaviors' 'behaviorListLen' times every 10
// milliseconds.
int behaviorListLen = 0;

// mailboxes is where our channel data comes in. A spectacle system can have
// up to 64 channels of behaviors, each of which is an int16.
int16 mailboxes[128];

volatile uint8 *I2C_Mem;

int main()
{
  CyGlobalIntEnable; /* Enable global interrupts. */

  // Initialize our PWM objects. After initialization, these objects will be
  // sending out a 1500us pulse one per 50ms, which should, for most servos,
  // cause the motor to take up a 50% position. 
  PWM_0_Start();
  PWM_1_Start();
  PWM_2_Start();
  PWM_3_Start();
  PWM_4_Start();

  // Clear out the mailbox cruft. We want all the mailboxes to start at zero.
  bzero(mailboxes, 128);

  // Point I2C_Mem to mailboxes, for more generalized I2C space addressing.
  I2C_Mem = (uint8*)mailboxes;

  I2C_Mem[PROG_ENABLE_REG] = 0;
  I2C_Mem[PROG_READY_REG] = 0;
  I2C_Mem[DATA_READY_REG] = 0;
  I2C_Mem[BOARD_ID_REG] = BOARD_ID;

  // This is the startup code for the incoming I2C peripheral. We first enable
  // the peripheral, then tell it what it needs to know about the memory it
  // will be looking at for later decision making.
  EZI2C_Start();
  EZI2C_EzI2CSetBuffer1(I2C_BUFFER_SIZE, I2C_BUFFER_RW_BOUNDARY, (uint8*)mailboxes);
  
  // Start the UART. This is *only* used during development.
  UART_Start();
  UART_UartPutString("Hello world\n");

  // ARM devices have an internal system tick which can be used as a timebase
  // without having to tie up additional system resources. Here we set it up to
  // point to our system tick ISR and configure it to occur once every 48000
  // clock ticks, which is once per millisecond on our 48MHz processor.
  CyIntSetSysVector((SysTick_IRQn + 16), tickISR);
  SysTick_Config(48000);
    
  // Configure some variables that will be used inside main().
  int32 _100HzTick = 0; // "tick" for 100Hz events
  int32 _2HzTick = 0;   // "tick" for 2Hz events
  int i = 0;            // loop variable

  // Here we configure our behaviors list to be some number of servo structs.

  behaviors = malloc(64*sizeof(struct servo));

  // Turn LED on. This is a useful check on whether or not the code made it
  // through the initialization process. If it did, the LED will come on. If
  // not, the LED stays off. If it gets hung in the loop, the LED will stop
  // blinking.
  LED_Write(1);
   
  for(;;)
  {
    //char buffer[32];
    // We are updating our servo behaviors at 100Hz. 
    if ((systemTimer - 10) > _100HzTick)
    {
      _100HzTick = systemTimer;

      
      uint32 rxBuffer = UART_UartGetChar();
      if (rxBuffer == 'r')
      {
        UART_UartPutString("r happened\n");
      } // End serial RXhandler

      if (I2C_Mem[PROG_ENABLE_REG] == 1)
      {
        program();
      }
      if (I2C_Mem[CONFIGURED_REG] == 1)
      {
        EZI2C_EzI2CSetAddress1(I2C_Mem[I2C_ADDR_REG]);
        I2C_Mem[CONFIGURED_REG] = 0;
        I2C_OUT_EN_Write(1);
      }

      // Behavior loop. We'll cycle through this loop for each behavior that we
      // received from the director board, checking that behavior's mailbox to
      // see if any data has been received for that channel. We'll then do
      // something based on that behavior.
      for (i = 0; i < behaviorListLen; i++)
      {

        if (behaviors[i].mode == SWEEP_RETURN)
        {
          sweepReturn(&behaviors[i]);
        }

        if (behaviors[i].mode == SWEEP)
        {
          sweep(&behaviors[i]);
        } // if (behaviors[i].mode == SWEEP)
        
        if (behaviors[i].mode == WAG)
        {
          wag(&behaviors[i]);
        } // if (behaviors[i].mode == WAG)

        if (behaviors[i].mode == GOTO)
        {
          goTo(&behaviors[i]);
        } // if (behaviors[i].mode == GOTO)
      } // for (i = 0; i < behaviorListLen; i++)
    } // End 100Hz timer

    if ((systemTimer - 500) > _2HzTick)
    {
      _2HzTick = systemTimer;
      if (LED_Read() != 0)
      {
        LED_Write(0);
      }
      else
      {
        LED_Write(1);
      } // if (LED_Read() != 0)
    } // End 2Hz timer
  }
}

struct servo copyBehavior(struct servo *copyMe)
{
  struct servo temp;
  memcpy(copyMe, &temp, sizeof(struct servo));
  return temp;
}


struct servo servoInit(uint8 channel, int16 threshold, uint8 servoID,
                       uint8 mode, uint16 posA, uint16 posB, uint32 dwellA,
                       uint32 dwellB)
{
  struct servo temp = {channel, threshold, servoID, mode, posA, posB, dwellA,
                       dwellB, 0, 0, 0, 0};
  return temp;
}

CY_ISR(tickISR)
{
  systemTimer++;
}

/* [] END OF FILE */

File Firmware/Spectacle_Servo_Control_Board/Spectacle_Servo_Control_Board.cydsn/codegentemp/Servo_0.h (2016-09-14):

/*******************************************************************************
* File Name: Servo_0.h  
* Version 2.20
*
* Description:
*  This file contains Pin function prototypes and register defines
*
********************************************************************************
* Copyright 2008-2015, Cypress Semiconductor Corporation.  All rights reserved.
* You may use this file only in accordance with the license, terms, conditions, 
* disclaimers, and limitations in the end user license agreement accompanying 
* the software package with which this file was provided.
*******************************************************************************/

#if !defined(CY_PINS_Servo_0_H) /* Pins Servo_0_H */
#define CY_PINS_Servo_0_H

#include "cytypes.h"
#include "cyfitter.h"
#include "Servo_0_aliases.h"


/***************************************
*     Data Struct Definitions
***************************************/

/**
* \addtogroup group_structures
* @{
*/
    
/* Structure for sleep mode support */
typedef struct
{
    uint32 pcState; /**< State of the port control register */
    uint32 sioState; /**< State of the SIO configuration */
    uint32 usbState; /**< State of the USBIO regulator */
} Servo_0_BACKUP_STRUCT;

/** @} structures */


/***************************************
*        Function Prototypes             
***************************************/
/**
* \addtogroup group_general
* @{
*/
uint8   Servo_0_Read(void);
void    Servo_0_Write(uint8 value);
uint8   Servo_0_ReadDataReg(void);
#if defined(Servo_0__PC) || (CY_PSOC4_4200L) 
    void    Servo_0_SetDriveMode(uint8 mode);
#endif
void    Servo_0_SetInterruptMode(uint16 position, uint16 mode);
uint8   Servo_0_ClearInterrupt(void);
/** @} general */

/**
* \addtogroup group_power
* @{
*/
void Servo_0_Sleep(void); 
void Servo_0_Wakeup(void);
/** @} power */


/***************************************
*           API Constants        
***************************************/
#if defined(Servo_0__PC) || (CY_PSOC4_4200L) 
    /* Drive Modes */
    #define Servo_0_DRIVE_MODE_BITS        (3)
    #define Servo_0_DRIVE_MODE_IND_MASK    (0xFFFFFFFFu >> (32 - Servo_0_DRIVE_MODE_BITS))

    /**
    * \addtogroup group_constants
    * @{
    */
        /** \addtogroup driveMode Drive mode constants
         * \brief Constants to be passed as "mode" parameter in the Servo_0_SetDriveMode() function.
         *  @{
         */
        #define Servo_0_DM_ALG_HIZ         (0x00u) /**< \brief High Impedance Analog   */
        #define Servo_0_DM_DIG_HIZ         (0x01u) /**< \brief High Impedance Digital  */
        #define Servo_0_DM_RES_UP          (0x02u) /**< \brief Resistive Pull Up       */
        #define Servo_0_DM_RES_DWN         (0x03u) /**< \brief Resistive Pull Down     */
        #define Servo_0_DM_OD_LO           (0x04u) /**< \brief Open Drain, Drives Low  */
        #define Servo_0_DM_OD_HI           (0x05u) /**< \brief Open Drain, Drives High */
        #define Servo_0_DM_STRONG          (0x06u) /**< \brief Strong Drive            */
        #define Servo_0_DM_RES_UPDWN       (0x07u) /**< \brief Resistive Pull Up/Down  */
        /** @} driveMode */
    /** @} group_constants */
#endif

/* Digital Port Constants */
#define Servo_0_MASK               Servo_0__MASK
#define Servo_0_SHIFT              Servo_0__SHIFT
#define Servo_0_WIDTH              1u

/**
* \addtogroup group_constants
* @{
*/
    /** \addtogroup intrMode Interrupt constants
     * \brief Constants to be passed as "mode" parameter in Servo_0_SetInterruptMode() function.
     *  @{
     */
        #define Servo_0_INTR_NONE      ((uint16)(0x0000u)) /**< \brief Disabled             */
        #define Servo_0_INTR_RISING    ((uint16)(0x5555u)) /**< \brief Rising edge trigger  */
        #define Servo_0_INTR_FALLING   ((uint16)(0xaaaau)) /**< \brief Falling edge trigger */
        #define Servo_0_INTR_BOTH      ((uint16)(0xffffu)) /**< \brief Both edge trigger    */
    /** @} intrMode */
/** @} group_constants */

/* SIO LPM definition */
#if defined(Servo_0__SIO)
    #define Servo_0_SIO_LPM_MASK       (0x03u)
#endif

/* USBIO definitions */
#if !defined(Servo_0__PC) && (CY_PSOC4_4200L)
    #define Servo_0_USBIO_ENABLE               ((uint32)0x80000000u)
    #define Servo_0_USBIO_DISABLE              ((uint32)(~Servo_0_USBIO_ENABLE))
    #define Servo_0_USBIO_SUSPEND_SHIFT        CYFLD_USBDEVv2_USB_SUSPEND__OFFSET
    #define Servo_0_USBIO_SUSPEND_DEL_SHIFT    CYFLD_USBDEVv2_USB_SUSPEND_DEL__OFFSET
    #define Servo_0_USBIO_ENTER_SLEEP          ((uint32)((1u << Servo_0_USBIO_SUSPEND_SHIFT) \
                                                        | (1u << Servo_0_USBIO_SUSPEND_DEL_SHIFT)))
    #define Servo_0_USBIO_EXIT_SLEEP_PH1       ((uint32)~((uint32)(1u << Servo_0_USBIO_SUSPEND_SHIFT)))
    #define Servo_0_USBIO_EXIT_SLEEP_PH2       ((uint32)~((uint32)(1u << Servo_0_USBIO_SUSPEND_DEL_SHIFT)))
    #define Servo_0_USBIO_CR1_OFF              ((uint32)0xfffffffeu)
#endif


/***************************************
*             Registers        
***************************************/
/* Main Port Registers */
#if defined(Servo_0__PC)
    /* Port Configuration */
    #define Servo_0_PC                 (* (reg32 *) Servo_0__PC)
#endif
/* Pin State */
#define Servo_0_PS                     (* (reg32 *) Servo_0__PS)
/* Data Register */
#define Servo_0_DR                     (* (reg32 *) Servo_0__DR)
/* Input Buffer Disable Override */
#define Servo_0_INP_DIS                (* (reg32 *) Servo_0__PC2)

/* Interrupt configuration Registers */
#define Servo_0_INTCFG                 (* (reg32 *) Servo_0__INTCFG)
#define Servo_0_INTSTAT                (* (reg32 *) Servo_0__INTSTAT)

/* "Interrupt cause" register for Combined Port Interrupt (AllPortInt) in GSRef component */
#if defined (CYREG_GPIO_INTR_CAUSE)
    #define Servo_0_INTR_CAUSE         (* (reg32 *) CYREG_GPIO_INTR_CAUSE)
#endif

/* SIO register */
#if defined(Servo_0__SIO)
    #define Servo_0_SIO_REG            (* (reg32 *) Servo_0__SIO)
#endif /* (Servo_0__SIO_CFG) */

/* USBIO registers */
#if !defined(Servo_0__PC) && (CY_PSOC4_4200L)
    #define Servo_0_USB_POWER_REG       (* (reg32 *) CYREG_USBDEVv2_USB_POWER_CTRL)
    #define Servo_0_CR1_REG             (* (reg32 *) CYREG_USBDEVv2_CR1)
    #define Servo_0_USBIO_CTRL_REG      (* (reg32 *) CYREG_USBDEVv2_USB_USBIO_CTRL)
#endif    
    
    
/***************************************
* The following code is DEPRECATED and 
* must not be used in new designs.
***************************************/
/**
* \addtogroup group_deprecated
* @{
*/
#define Servo_0_DRIVE_MODE_SHIFT       (0x00u)
#define Servo_0_DRIVE_MODE_MASK        (0x07u << Servo_0_DRIVE_MODE_SHIFT)
/** @} deprecated */

#endif /* End Pins Servo_0_H */


/* [] END OF FILE */

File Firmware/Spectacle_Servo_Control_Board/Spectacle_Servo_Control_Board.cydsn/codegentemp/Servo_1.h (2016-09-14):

/*******************************************************************************
* File Name: Servo_1.h  
* Version 2.20
*
* Description:
*  This file contains Pin function prototypes and register defines
*
********************************************************************************
* Copyright 2008-2015, Cypress Semiconductor Corporation.  All rights reserved.
* You may use this file only in accordance with the license, terms, conditions, 
* disclaimers, and limitations in the end user license agreement accompanying 
* the software package with which this file was provided.
*******************************************************************************/

#if !defined(CY_PINS_Servo_1_H) /* Pins Servo_1_H */
#define CY_PINS_Servo_1_H

#include "cytypes.h"
#include "cyfitter.h"
#include "Servo_1_aliases.h"


/***************************************
*     Data Struct Definitions
***************************************/

/**
* \addtogroup group_structures
* @{
*/
    
/* Structure for sleep mode support */
typedef struct
{
    uint32 pcState; /**< State of the port control register */
    uint32 sioState; /**< State of the SIO configuration */
    uint32 usbState; /**< State of the USBIO regulator */
} Servo_1_BACKUP_STRUCT;

/** @} structures */


/***************************************
*        Function Prototypes             
***************************************/
/**
* \addtogroup group_general
* @{
*/
uint8   Servo_1_Read(void);
void    Servo_1_Write(uint8 value);
uint8   Servo_1_ReadDataReg(void);
#if defined(Servo_1__PC) || (CY_PSOC4_4200L) 
    void    Servo_1_SetDriveMode(uint8 mode);
#endif
void    Servo_1_SetInterruptMode(uint16 position, uint16 mode);
uint8   Servo_1_ClearInterrupt(void);
/** @} general */

/**
* \addtogroup group_power
* @{
*/
void Servo_1_Sleep(void); 
void Servo_1_Wakeup(void);
/** @} power */


/***************************************
*           API Constants        
***************************************/
#if defined(Servo_1__PC) || (CY_PSOC4_4200L) 
    /* Drive Modes */
    #define Servo_1_DRIVE_MODE_BITS        (3)
    #define Servo_1_DRIVE_MODE_IND_MASK    (0xFFFFFFFFu >> (32 - Servo_1_DRIVE_MODE_BITS))

    /**
    * \addtogroup group_constants
    * @{
    */
        /** \addtogroup driveMode Drive mode constants
         * \brief Constants to be passed as "mode" parameter in the Servo_1_SetDriveMode() function.
         *  @{
         */
        #define Servo_1_DM_ALG_HIZ         (0x00u) /**< \brief High Impedance Analog   */
        #define Servo_1_DM_DIG_HIZ         (0x01u) /**< \brief High Impedance Digital  */
        #define Servo_1_DM_RES_UP          (0x02u) /**< \brief Resistive Pull Up       */
        #define Servo_1_DM_RES_DWN         (0x03u) /**< \brief Resistive Pull Down     */
        #define Servo_1_DM_OD_LO           (0x04u) /**< \brief Open Drain, Drives Low  */
        #define Servo_1_DM_OD_HI           (0x05u) /**< \brief Open Drain, Drives High */
        #define Servo_1_DM_STRONG          (0x06u) /**< \brief Strong Drive            */
        #define Servo_1_DM_RES_UPDWN       (0x07u) /**< \brief Resistive Pull Up/Down  */
        /** @} driveMode */
    /** @} group_constants */
#endif

/* Digital Port Constants */
#define Servo_1_MASK               Servo_1__MASK
#define Servo_1_SHIFT              Servo_1__SHIFT
#define Servo_1_WIDTH              1u

/**
* \addtogroup group_constants
* @{
*/
    /** \addtogroup intrMode Interrupt constants
     * \brief Constants to be passed as "mode" parameter in Servo_1_SetInterruptMode() function.
     *  @{
     */
        #define Servo_1_INTR_NONE      ((uint16)(0x0000u)) /**< \brief Disabled             */
        #define Servo_1_INTR_RISING    ((uint16)(0x5555u)) /**< \brief Rising edge trigger  */
        #define Servo_1_INTR_FALLING   ((uint16)(0xaaaau)) /**< \brief Falling edge trigger */
        #define Servo_1_INTR_BOTH      ((uint16)(0xffffu)) /**< \brief Both edge trigger    */
    /** @} intrMode */
/** @} group_constants */

/* SIO LPM definition */
#if defined(Servo_1__SIO)
    #define Servo_1_SIO_LPM_MASK       (0x03u)
#endif

/* USBIO definitions */
#if !defined(Servo_1__PC) && (CY_PSOC4_4200L)
    #define Servo_1_USBIO_ENABLE               ((uint32)0x80000000u)
    #define Servo_1_USBIO_DISABLE              ((uint32)(~Servo_1_USBIO_ENABLE))
    #define Servo_1_USBIO_SUSPEND_SHIFT        CYFLD_USBDEVv2_USB_SUSPEND__OFFSET
    #define Servo_1_USBIO_SUSPEND_DEL_SHIFT    CYFLD_USBDEVv2_USB_SUSPEND_DEL__OFFSET
    #define Servo_1_USBIO_ENTER_SLEEP          ((uint32)((1u << Servo_1_USBIO_SUSPEND_SHIFT) \
                                                        | (1u << Servo_1_USBIO_SUSPEND_DEL_SHIFT)))
    #define Servo_1_USBIO_EXIT_SLEEP_PH1       ((uint32)~((uint32)(1u << Servo_1_USBIO_SUSPEND_SHIFT)))
    #define Servo_1_USBIO_EXIT_SLEEP_PH2       ((uint32)~((uint32)(1u << Servo_1_USBIO_SUSPEND_DEL_SHIFT)))
    #define Servo_1_USBIO_CR1_OFF              ((uint32)0xfffffffeu)
#endif


/***************************************
*             Registers        
***************************************/
/* Main Port Registers */
#if defined(Servo_1__PC)
    /* Port Configuration */
    #define Servo_1_PC                 (* (reg32 *) Servo_1__PC)
#endif
/* Pin State */
#define Servo_1_PS                     (* (reg32 *) Servo_1__PS)
/* Data Register */
#define Servo_1_DR                     (* (reg32 *) Servo_1__DR)
/* Input Buffer Disable Override */
#define Servo_1_INP_DIS                (* (reg32 *) Servo_1__PC2)

/* Interrupt configuration Registers */
#define Servo_1_INTCFG                 (* (reg32 *) Servo_1__INTCFG)
#define Servo_1_INTSTAT                (* (reg32 *) Servo_1__INTSTAT)

/* "Interrupt cause" register for Combined Port Interrupt (AllPortInt) in GSRef component */
#if defined (CYREG_GPIO_INTR_CAUSE)
    #define Servo_1_INTR_CAUSE         (* (reg32 *) CYREG_GPIO_INTR_CAUSE)
#endif

/* SIO register */
#if defined(Servo_1__SIO)
    #define Servo_1_SIO_REG            (* (reg32 *) Servo_1__SIO)
#endif /* (Servo_1__SIO_CFG) */

/* USBIO registers */
#if !defined(Servo_1__PC) && (CY_PSOC4_4200L)
    #define Servo_1_USB_POWER_REG       (* (reg32 *) CYREG_USBDEVv2_USB_POWER_CTRL)
    #define Servo_1_CR1_REG             (* (reg32 *) CYREG_USBDEVv2_CR1)
    #define Servo_1_USBIO_CTRL_REG      (* (reg32 *) CYREG_USBDEVv2_USB_USBIO_CTRL)
#endif    
    
    
/***************************************
* The following code is DEPRECATED and 
* must not be used in new designs.
***************************************/
/**
* \addtogroup group_deprecated
* @{
*/
#define Servo_1_DRIVE_MODE_SHIFT       (0x00u)
#define Servo_1_DRIVE_MODE_MASK        (0x07u << Servo_1_DRIVE_MODE_SHIFT)
/** @} deprecated */

#endif /* End Pins Servo_1_H */


/* [] END OF FILE */

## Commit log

2016-03-21 Added LED, buttons
    [Spectacle_Button_Board.brd, Spectacle_Button_Board.sch]
2016-05-11 Laid out board
    [Spectacle_Button_Board.brd, Spectacle_Button_Board.sch]
2016-07-15 Derived from Button Board
    [Spectacle_Button_Board.brd, Spectacle_Button_Board.sch, Spectacle_Servo_Control_Board.brd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]
2016-07-18 Okay'ed some DRC errors
    [Spectacle_Servo_Control_Board.brd]
2016-08-01 Changes from design review, initial checklist pass
    [Spectacle_Servo_Control_Board.brd, Spectacle_Servo_Control_Board.sch]
2016-08-02 Revised from feedback from QC
    [Spectacle_Servo_Control_Board.brd, Spectacle_Servo_Control_Board.sch]
2016-09-14 Firmware check-in Contains a test firmware for Arduino and an intermediate working firmware for the Spectacle board which can receive over I2C and respond to commands sent over I2C.
2016-10-11 Added downstream power control circuitry
    [Spectacle_Servo_Control_Board.brd, Spectacle_Servo_Control_Board.sch]
2016-10-19 Add servo.h, .project, in/out labels
    [Spectacle_Servo_Control_Board.brd, Spectacle_Servo_Control_Board.sch]
2016-10-25 Change board and repo name
    [Spectacle_Motion_Board.brd, Spectacle_Motion_Board.sch]
2016-10-25 Feedback from review incorporated, ready for qc review
    [Spectacle_Motion_Board.brd, Spectacle_Motion_Board.sch]
2016-10-31 Chg I2C pullup value
    [Spectacle_Motion_Board.brd, Spectacle_Motion_Board.sch]
2016-11-01 Feedback from reviews incorporated
    [Spectacle_Motion_Board.brd, Spectacle_Motion_Board.sch]
2016-11-01 Increased inner pour coverage
    [Spectacle_Motion_Board.brd]
2016-11-01 Added and fixed some product IDs
    [Spectacle_Motion_Board.brd, Spectacle_Motion_Board.sch]
2017-01-23 Touchups for v10
    [Spectacle_Motion_Board.brd, Spectacle_Motion_Board.sch]

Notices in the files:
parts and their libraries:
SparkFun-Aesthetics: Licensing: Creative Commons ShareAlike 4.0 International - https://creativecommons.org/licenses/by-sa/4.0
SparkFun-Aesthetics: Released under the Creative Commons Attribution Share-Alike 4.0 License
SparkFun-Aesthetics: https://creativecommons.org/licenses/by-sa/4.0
